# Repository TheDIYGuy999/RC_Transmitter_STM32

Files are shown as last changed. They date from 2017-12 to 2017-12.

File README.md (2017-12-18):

# This is an Arduino 2.4GHz radio and IR transmitter for STM32
## Features:
- IR transmitter for "LEGO" Powerfunctions and trains as well as for "MECCANO" motors
- 2.4GHz radio transmitter for RC cars, helicopters etc.
- 4 analog axes, 2 mode switches (joystick buttons)
- 1 potentiometer for adjustments like the MRSC stability control
- 4 push buttons for transmission mode and vehicle selection as well as menu navigation
- 10 seletcable vehicle addresses, so you can use it for more than one vehicle
- 3.3V, 72MHz STM32F103C8T6 ARM board
- Atmel AVR version see: https://github.com/TheDIYGuy999/RC_Transmitter
- 2.4GHz NRF24L01 radio module
- Support for 0.96" I2C OLED.
- Configuration menu for: Channel direction reversing, servo travel adjustment (independent for each vehicle)
- Configuration values are stored in EEPROM
- NRF24L01+PA+LNA SMA radio modules with power amplifier are supported from board version 1.1
- very compact
- Eagle schematic will follow
- PONG Game included (runs much faster than on the Atmel AVR version)

## Changelog:

New in V 2.0:
- Initial commit starting with V2.0, because the features are the same as in V2.0 for Atmel ARM MCU's
- Pinout according to the software comments. An Eagle schematic will follow later
- Works together with my Atmel AVR based receivers or the transmitter in "Tester Mode"
- OLED now driven by the u8g2 library in "full buffer" mode. This is much faster, but requires more RAM (no problem on the STM32)
- Lego IR ist tested
- Meccano IR should work in theory, but the signal was only tested with an oscilloscope
- The emulated STM32 EEPROM seems to work properly, but the required "eepromHandler.h" is entirely new
- This version may still contain bugs. It was only tested on a breadboard

New in V 2.01:
- Battery voltage detection bug fixed

## Usage

See pictures

The biggest and the smallest vehicle:


The Atmel AVR version:


The STM32 test rig on a breadboard:
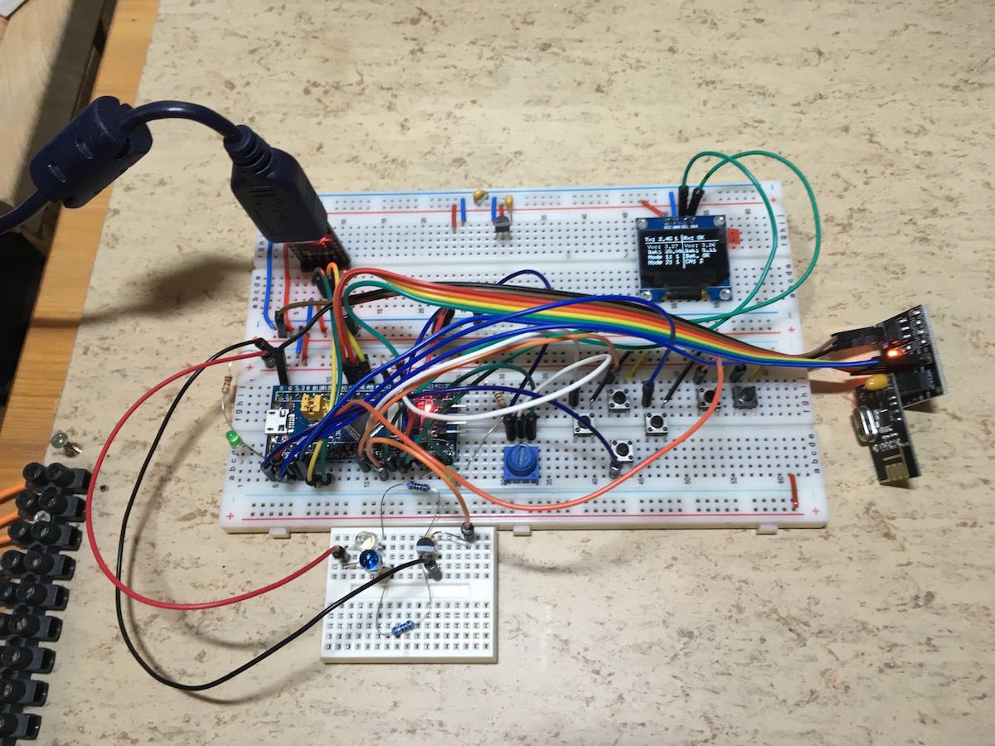
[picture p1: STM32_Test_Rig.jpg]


(c) 2017 TheDIYGuy999

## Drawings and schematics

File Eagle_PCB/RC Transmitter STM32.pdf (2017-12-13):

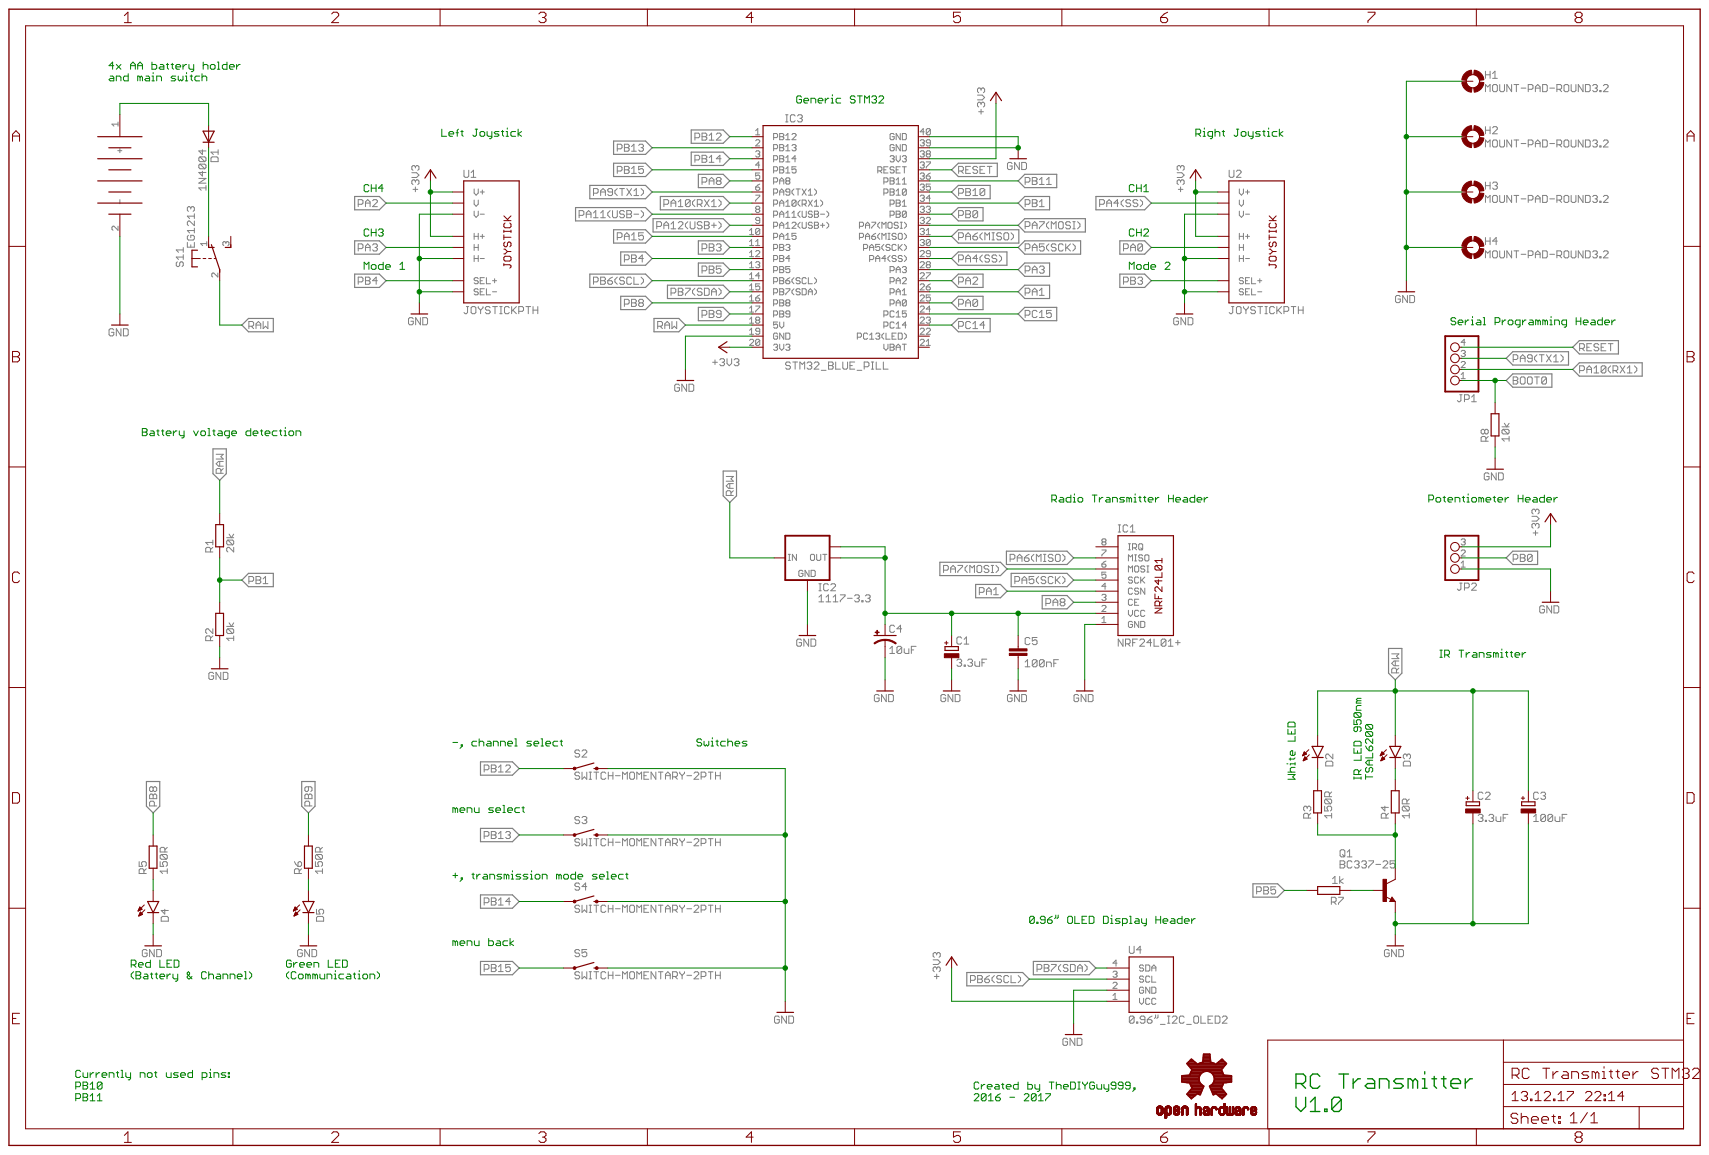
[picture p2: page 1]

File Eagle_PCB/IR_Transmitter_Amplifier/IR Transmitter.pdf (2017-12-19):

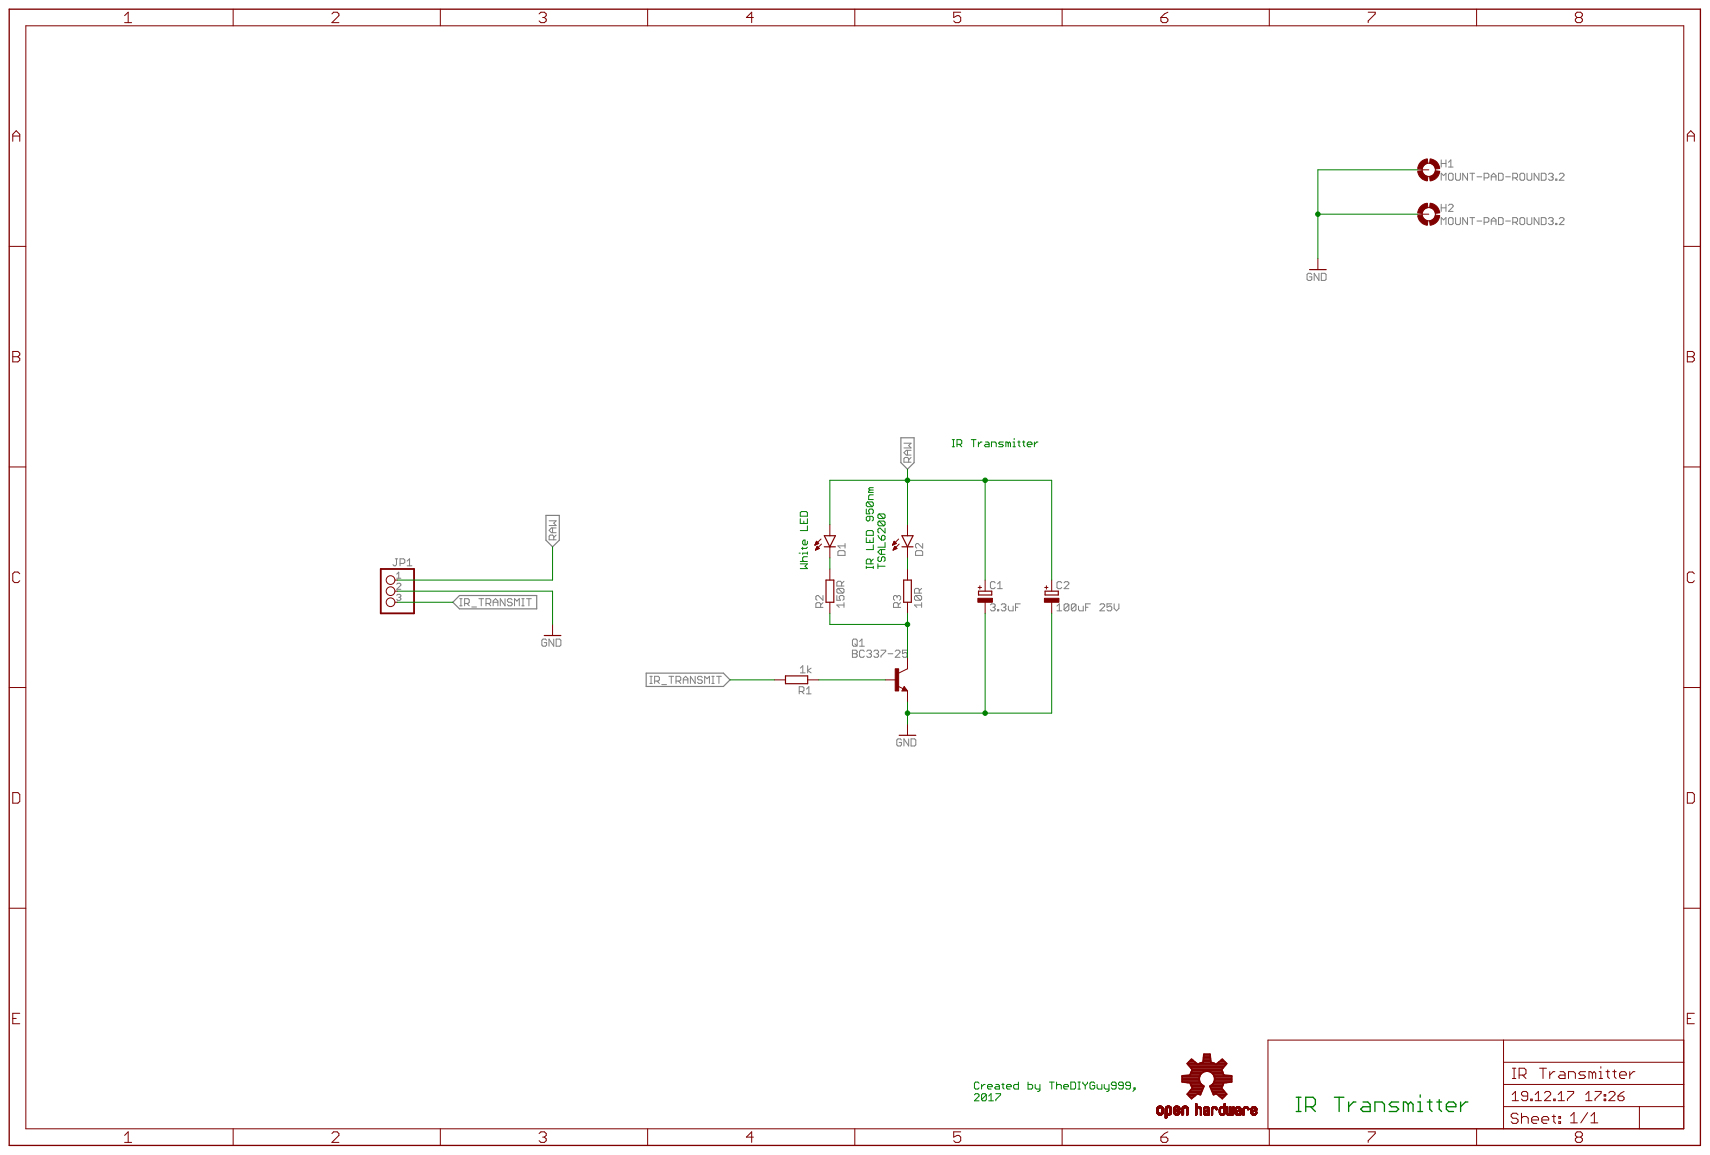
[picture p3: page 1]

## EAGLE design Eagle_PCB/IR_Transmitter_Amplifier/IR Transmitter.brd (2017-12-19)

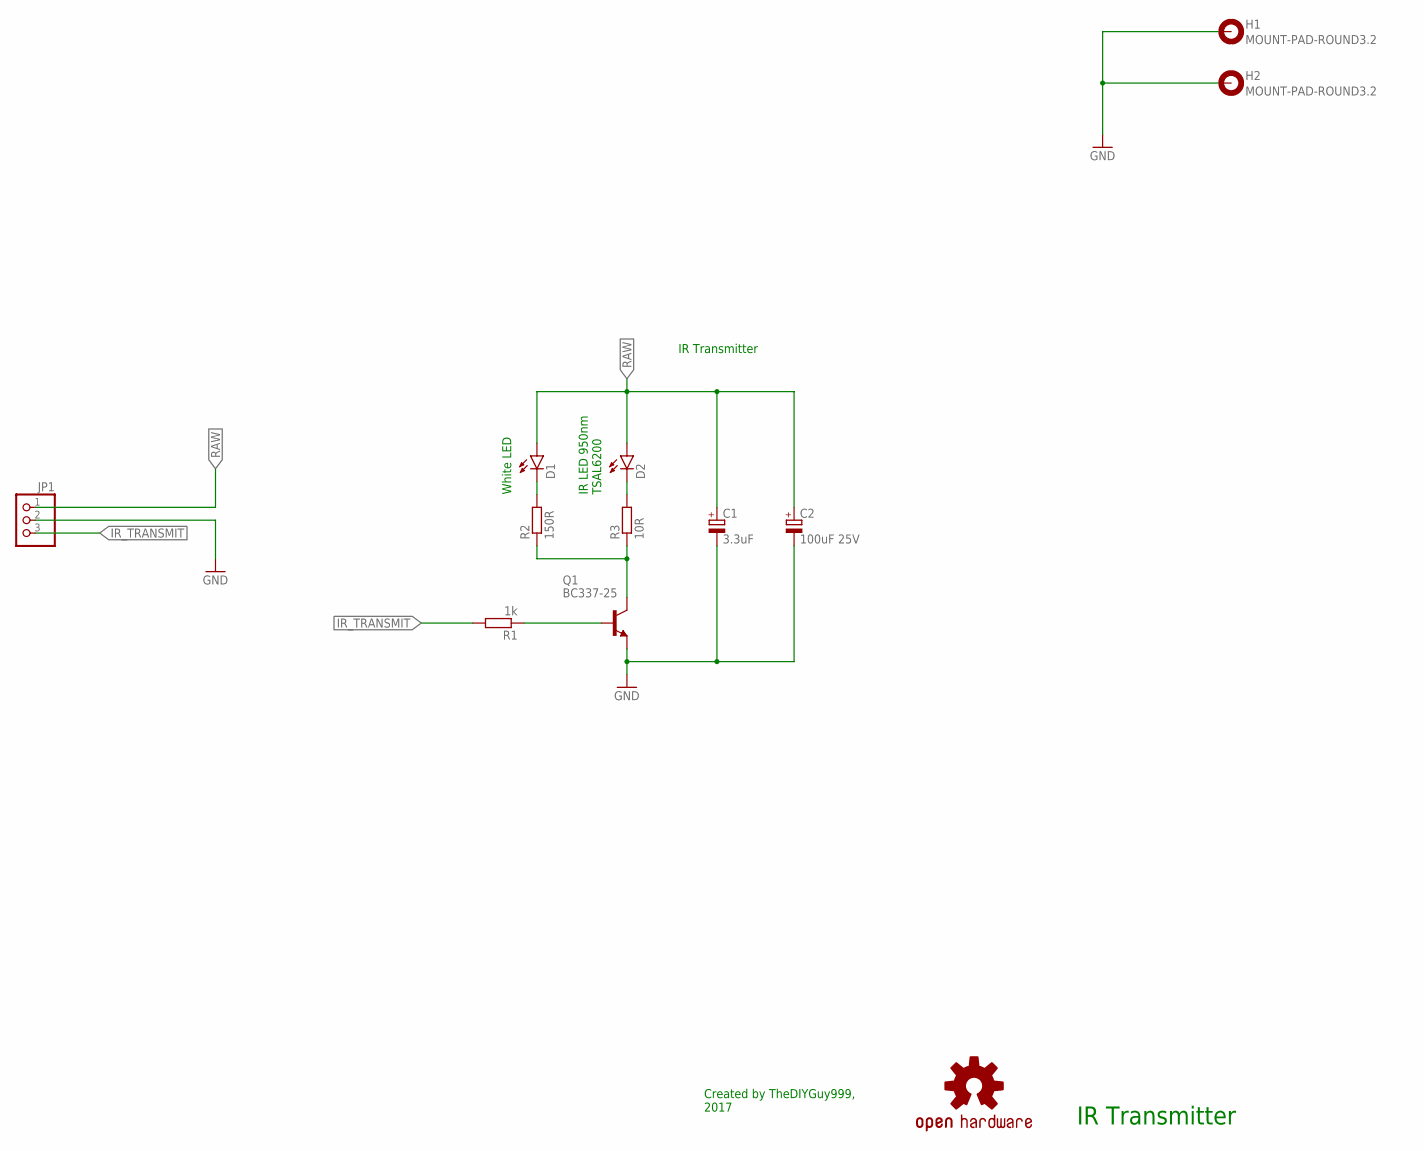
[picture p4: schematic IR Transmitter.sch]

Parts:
C1: 3.3uF; B45181A
C2: 100uF 25V; E2,5-7
D1, D2: LED5MM
H1, H2: MOUNT-PAD-ROUND3.2; 3,2-PAD
JP1: PINHD-1X3; 1X03
LOGO1: OSHW-LOGOM; OSHW-LOGO-M
Q1: BC337-25; TO92
R1: 1k; 0207/2V
R2: 150R; 0207/2V
R3: 10R; 0207/2V

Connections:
GND: C1.-, C2.-, H1.B3,2, H2.B3,2, JP1.2, Q1.1 (E)
IR_TRANSMIT: JP1.3, R1.2
unnamed: Q1.3 (C), R2.1, R3.1
unnamed: D2.K (C), R3.2
unnamed: Q1.2 (B), R1.1
unnamed: D1.K (C), R2.2
RAW: C1.+, C2.+, D1.A, D2.A, JP1.1

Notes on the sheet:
IR Transmitter
White LED
IR LED 950nm TSAL6200
Created by TheDIYGuy999, 2017

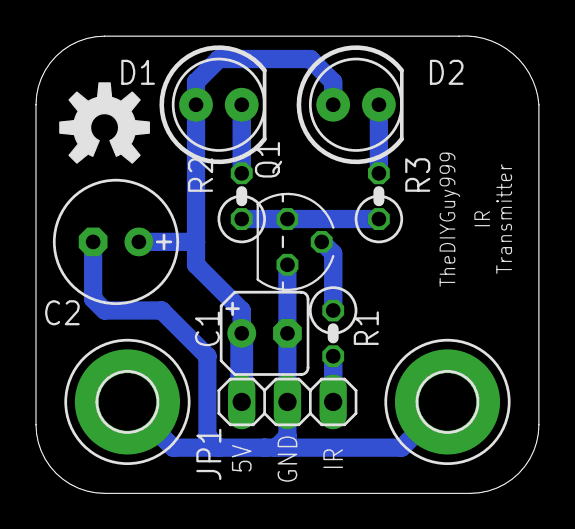
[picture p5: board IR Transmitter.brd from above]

Board: 2 copper layers, 27.9 x 25.4 mm, 12 parts (0 on the bottom side), 7 nets.

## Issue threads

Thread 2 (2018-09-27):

Receiver for stm32

yudimoss, 2018-09-27:
Would you mind to make arduino radio 2.4ghz receiver for stm32?

TheDIYGuy999, 2018-09-28:
I don't see the point. The ATmega328P has more than enough processing power for the receiver. The existing Micro RC receiver is fully compatible with the STM32 transmitter.

yudimoss, 2018-09-28:
Oh I see

Closed 2018-09-28.

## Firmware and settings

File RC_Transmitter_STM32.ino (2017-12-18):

// Micro RC Project. A tiny little 2.4GHz and LEGO "Power Functions" / "MECCANO" IR RC transmitter!
// 3.3V, 72MHz STM32F103C8T6 ARM board
// Atmel AVR version see: https://github.com/TheDIYGuy999/RC_Transmitter
// 2.4GHz NRF24L01 radio module
// SSD 1306 128 x 63 0.96" OLED
// Custom PCB will follow
// Menu for the following adjustments:
// -Channel reversing
// -Channel travel limitation adjustable in steps of 5%
// -Value changes are stored in EEPROM, individually per vehicle
// Radio transmitter tester included (press "Select" button during power up)
// NRF24L01+PA+LNA SMA radio modules with power amplifier are also supported
// ATARI PONG game :-) Press the "Back" button during power on to start it

const float codeVersion = 2.01; // Software revision

//
// =======================================================================================================
// BUILD OPTIONS (comment out unneeded options)
// =======================================================================================================
//

//#define DEBUG // if not commented out, Serial.print() is active! For debugging only!!
//#define OLED_DEBUG // if not commented out, an additional diagnostics screen is shown during startup

//
// =======================================================================================================
// INCLUDE LIRBARIES
// =======================================================================================================
//

// Libraries
#include <Wire.h>
#include <SPI.h>
#include <RF24_STM32.h> // https://github.com/TheDIYGuy999/RF24_STM32
#include <EEPROM.h> // Part of https://github.com/rogerclarkmelbourne/Arduino_STM32
#include <LegoIr.h> // https://github.com/TheDIYGuy999/LegoIr
#include <statusLED.h> // https://github.com/TheDIYGuy999/statusLED
#include <U8g2lib.h> // https://github.com/olikraus/u8g2

// Tabs (.h files in the sketch directory) see further down

//
// =======================================================================================================
// PIN ASSIGNMENTS & GLOBAL VARIABLES
// =======================================================================================================
//

// Is the radio or IR transmission mode active?
byte transmissionMode = 1; // Radio mode is active by default

// Select operation trannsmitter operation mode
byte operationMode = 0; // Start in transmitter mode (0 = transmitter mode, 1 = tester mode, 2 = game mode)

// Vehicle address
int vehicleNumber = 1; // Vehicle number one is active by default

// Radio channels (126 channels are supported)
byte chPointer = 0; // Channel 1 (the first entry of the array) is active by default
const byte NRFchannel[] {
  1, 2
};

// the ID number of the used "radio pipe" must match with the selected ID on the transmitter!
// 10 ID's are available @ the moment
const uint64_t pipeOut[] = {
  0xE9E8F0F0B1LL, 0xE9E8F0F0B2LL, 0xE9E8F0F0B3LL, 0xE9E8F0F0B4LL, 0xE9E8F0F0B5LL,
  0xE9E8F0F0B6LL, 0xE9E8F0F0B7LL, 0xE9E8F0F0B8LL, 0xE9E8F0F0B9LL, 0xE9E8F0F0B0LL
};
const int maxVehicleNumber = (sizeof(pipeOut) / (sizeof(uint64_t)));

// Hardware configuration: Set up nRF24L01 radio on hardware SPI bus & pins PA8 (CE) & PA1 (CSN)
RF24 radio(PA8, PA1);

// The size of this struct should not exceed 32 bytes
struct RcData {
  byte axis1; // Aileron (Steering for car)
  byte axis2; // Elevator
  byte axis3; // Throttle
  byte axis4; // Rudder
  boolean mode1 = false; // Mode1 (toggle speed limitation)
  boolean mode2 = false; // Mode2 (toggle acc. / dec. limitation)
  boolean momentary1 = false; // Momentary push button
  byte pot1; // Potentiometer
} __attribute__((packed, aligned(2))); // no padding, aligned to an address that is divisible by 2 (keeps it compatible with AVR)
RcData data;

// This struct defines data, which are embedded inside the ACK payload
struct ackPayload {
  float vcc; // vehicle vcc voltage
  float batteryVoltage; // vehicle battery voltage
  boolean batteryOk; // the vehicle battery voltage is OK!
  byte channel = 1; // the channel number
} __attribute__((packed, aligned(2))); // no padding, aligned to an address that is divisible by 2 (keeps it compatible with AVR)
ackPayload payload;

// Did the receiver acknowledge the sent data?
boolean transmissionState;

// LEGO powerfunctions IR
LegoIr pf;
int pfChannel;
const int pfMaxAddress = 3;

// Configuration arrays
const int servos = 4;
const byte entries = 44; // Entries per array

//Joystick reversing
uint16_t joystickReversed[maxVehicleNumber + 1][servos] = { // 1 + 10 Vehicle Addresses, 4 Servos
  {false, false, false, false}, // Address 0 used for EEPROM initialisation

  {false, false, false, false}, // Address 1
  {false, false, false, false}, // Address 2
  {false, false, false, false}, // Address 3
  {false, false, false, false}, // Address 4
  {false, false, false, false}, // Address 5
  {false, false, false, false}, // Address 6
  {false, false, false, false}, // Address 7
  {false, false, false, false}, // Address 8
  {false, false, false, false}, // Address 9
  {false, false, false, false}, // Address 10
};

//Joystick percent negative
uint16_t joystickPercentNegative[maxVehicleNumber + 1][servos] = { // 1 + 10 Vehicle Addresses, 4 Servos
  {100, 100, 100, 100}, // Address 0 not used

  {100, 100, 100, 100}, // Address 1
  {100, 100, 100, 100}, // Address 2
  {100, 100, 100, 100}, // Address 3
  {100, 100, 100, 100}, // Address 4
  {100, 100, 100, 100}, // Address 5
  {100, 100, 100, 100}, // Address 6
  {100, 100, 100, 100}, // Address 7
  {100, 100, 100, 100}, // Address 8
  {100, 100, 100, 100}, // Address 9
  {100, 100, 100, 100}, // Address 10
};

//Joystick percent positive
uint16_t joystickPercentPositive[maxVehicleNumber + 1][servos] = { // 1 + 10 Vehicle Addresses, 4 Servos
  {100, 100, 100, 100}, // Address 0 not used

  {100, 100, 100, 100}, // Address 1
  {100, 100, 100, 100}, // Address 2
  {100, 100, 100, 100}, // Address 3
  {100, 100, 100, 100}, // Address 4
  {100, 100, 100, 100}, // Address 5
  {100, 100, 100, 100}, // Address 6
  {100, 100, 100, 100}, // Address 7
  {100, 100, 100, 100}, // Address 8
  {100, 100, 100, 100}, // Address 9
  {100, 100, 100, 100}, // Address 10
};

// TX voltages
boolean batteryOkTx = false;
#define BATTERY_DETECT_PIN PB1 // The 20k & 10k battery detection voltage divider is connected to pin PB1
float txVcc;
float txBatt;

// Joysticks
#define JOYSTICK_1 PA4
#define JOYSTICK_2 PA0
#define JOYSTICK_3 PA3
#define JOYSTICK_4 PA2

// Potentiometer
#define POT_1 PB0

// Joystick push buttons
#define JOYSTICK_BUTTON_LEFT PB4
#define JOYSTICK_BUTTON_RIGHT PB3

byte leftJoystickButtonState;
byte rightJoystickButtonState;

// Buttons
#define BUTTON_LEFT PB12 // - or channel select
#define BUTTON_RIGHT PB14 // + or transmission mode select
#define BUTTON_SEL PB13 // select button for menu
#define BUTTON_BACK PB15 // back button for menu

byte leftButtonState = 7; // init states with 7 (see macro below)!
byte rightButtonState = 7;
byte selButtonState = 7;
byte backButtonState = 7;

// macro for detection of rising edge and debouncing
/*the state argument (which must be a variable) records the current and the last 3 reads
  by shifting one bit to the left at each read and bitwise anding with 15 (=0b1111).
  If the value is 7(=0b0111) we have one raising edge followed by 3 consecutive 1's.
  That would qualify as a debounced raising edge*/
#define DRE(signal, state) (state=(state<<1)|(signal&1)&15)==7

// Status LED objects (false = not inverted)
statusLED greenLED(false); // green: ON = ransmitter ON, flashing = Communication with vehicle OK
statusLED redLED(false); // red: ON = battery empty

// OLED display SSD1306
// SDA = PB7, SCL = PB6 (Hardware I2C)
U8G2_SSD1306_128X64_NONAME_F_HW_I2C u8g2(U8G2_R0, /* reset=*/ U8X8_PIN_NONE);

int activeScreen = 0; // the currently displayed screen number (0 = splash screen)
boolean displayLocked = true;
byte menuRow = 0; // Menu active cursor line

//
// =======================================================================================================
// INCLUDE TABS (header files in sketch directory)
// =======================================================================================================
//

#include "readVCC.h"
#include "eepromHandler.h"
#include "transmitterConfig.h"
#include "MeccanoIr.h" // https://github.com/TheDIYGuy999/MeccanoIr
#include "pong.h" // A little pong game :-)

//
// =======================================================================================================
// RADIO SETUP
// =======================================================================================================
//

void setupRadio() {
  radio.begin();
  radio.setChannel(NRFchannel[chPointer]);

  radio.powerUp();

  // Set Power Amplifier (PA) level to one of four levels: RF24_PA_MIN, RF24_PA_LOW, RF24_PA_HIGH and RF24_PA_MAX
  if (boardVersion < 1.1 ) radio.setPALevel(RF24_PA_MIN); // No independent NRF24L01 3.3 PSU, so only "MIN" transmission level allowed
  else radio.setPALevel(RF24_PA_MAX); // Independent NRF24L01 3.3 PSU, so "FULL" transmission level allowed

  radio.setDataRate(RF24_250KBPS);
  radio.setAutoAck(pipeOut[vehicleNumber - 1], true); // Ensure autoACK is enabled
  radio.enableAckPayload();
  radio.enableDynamicPayloads();
  radio.setRetries(5, 5);                  // 5x250us delay (blocking!!), max. 5 retries
  //radio.setCRCLength(RF24_CRC_8);          // Use 8-bit CRC for performance*/

#ifdef DEBUG
  radio.printDetails();
  delay(1800);
#endif

  // All axes to neutral position
  data.axis1 = 50;
  data.axis2 = 50;
  data.axis3 = 50;
  data.axis4 = 50;

  // Transmitter
  if (operationMode == 0) {
    radio.openWritingPipe(pipeOut[vehicleNumber - 1]); // Vehicle Number 1 = Array number 0, so -1!
    radio.write(&data, sizeof(RcData));
  }

  // Receiver (radio tester mode)
  if (operationMode == 1) {
    radio.openReadingPipe(1, pipeOut[vehicleNumber - 1]);
    radio.startListening();
  }
}

//
// =======================================================================================================
// LEGO POWERFUNCTIONS SETUP
// =======================================================================================================
//

void setupPowerfunctions() {
  pfChannel = vehicleNumber - 1;  // channel 0 - 3 is labelled as 1 - 4 on the LEGO devices!

  if (pfChannel > pfMaxAddress) pfChannel = pfMaxAddress;

  pf.begin(PB5, pfChannel);  // Pin PB5, channel 0 - 3
}

//
// =======================================================================================================
// MAIN ARDUINO SETUP (1x during startup)
// =======================================================================================================
//

void setup() {

#ifdef DEBUG
  Serial.begin(115200);
  printf_begin();
  delay(3000);
#endif

  // Disable STM32 JTAG debug pins! Allows to use pin PB3 and PB4
  // See: http://www.stm32duino.com/viewtopic.php?f=3&t=2084&p=27945&hilit=pb3#p27916
  disableDebugPorts();

  // ADC setup for VCC readout
  setup_vcc_sensor();

  // LED setup
  greenLED.begin(PB9); // Green LED on pin PB9
  redLED.begin(PB8); // Red LED on pin PB8

  // Pinmodes (all other pinmodes are handled inside libraries)
  pinMode(JOYSTICK_BUTTON_LEFT, INPUT_PULLUP);
  pinMode(JOYSTICK_BUTTON_RIGHT, INPUT_PULLUP);
  pinMode(BUTTON_LEFT, INPUT_PULLUP);
  pinMode(BUTTON_RIGHT, INPUT_PULLUP);
  pinMode(BUTTON_SEL, INPUT_PULLUP);
  pinMode(BUTTON_BACK, INPUT_PULLUP);

  pinMode(JOYSTICK_1, INPUT_ANALOG);
  pinMode(JOYSTICK_2, INPUT_ANALOG);
  pinMode(JOYSTICK_3, INPUT_ANALOG);
  pinMode(JOYSTICK_4, INPUT_ANALOG);

  pinMode(POT_1, INPUT_ANALOG);

  // EEPROM setup
  setupEeprom();

  if (joystickReversed[0][0] || (!digitalRead(BUTTON_BACK) && !digitalRead(BUTTON_SEL))) { // 65535 is EEPROM default after a program download,
    // this indicates that we have to initialise the EEPROM with our default values! Or manually triggered with
    // both "SEL" & "BACK" buttons pressed during switching on!
    writeEepromDefaults(); // then write defaults to EEPROM
    readEeprom(); // and fill the arrays with the new EEPROM values!

  }

  // Switch to radio tester mode, if "Select" button is pressed
  if (digitalRead(BUTTON_BACK) && !digitalRead(BUTTON_SEL)) {
    operationMode = 1;
  }

  // Switch to game mode, if "Back" button is pressed
  if (!digitalRead(BUTTON_BACK) && digitalRead(BUTTON_SEL)) {
    operationMode = 2;
  }

  // Joystick setup
  JoystickOffset(); // Compute all joystick center points
  readJoysticks(); // Then do the first jocstick read

  // Radio setup
  setupRadio();

  // LEGO Powerfunctions setup
  setupPowerfunctions();

  // Display setup
  u8g2.begin();
  u8g2.setFontRefHeightExtendedText();
  u8g2.setFont(u8g_font_6x10);

  // Splash screen
  checkBattery();
  activeScreen = 0; // 0 = splash screen active
  drawDisplay();
#ifdef OLED_DEBUG
  activeScreen = 100; // switch to the diagnostics screen
  delay(1500);
  drawDisplay();
#endif
  activeScreen = 1; // switch to the main screen
  delay(1500);
}

//
// =======================================================================================================
// BUTTONS
// =======================================================================================================
//

// Sub function for channel travel adjustment and limitation --------------------------------------
void travelAdjust(boolean upDn) {
  int16_t inc = 5;
  if (upDn) inc = 5; // Direction +
  else inc = -5; // -

  if ( (menuRow & 0x01) == 0) {// even (2nd column)
    joystickPercentPositive[vehicleNumber][(menuRow - 6) / 2 ] += inc; // row 6 - 12 = 0 - 3
  }
  else { // odd (1st column)
    joystickPercentNegative[vehicleNumber][(menuRow - 5) / 2 ] += inc;  // row 5 - 11 = 0 - 3
  }
  joystickPercentPositive[vehicleNumber][(menuRow - 6) / 2 ] = constrain(joystickPercentPositive[vehicleNumber][(menuRow - 6) / 2 ], 20, 100);
  joystickPercentNegative[vehicleNumber][(menuRow - 5) / 2 ] = constrain(joystickPercentNegative[vehicleNumber][(menuRow - 5) / 2 ], 20, 100);
}

// Main buttons function --------------------------------------------------------------------------
void readButtons() {

  // Every 10 ms
  static unsigned long lastTrigger;
  if (millis() - lastTrigger >= 10) {
    lastTrigger = millis();

    // Left joystick button (Mode 1)
    if (DRE(digitalRead(JOYSTICK_BUTTON_LEFT), leftJoystickButtonState) && (transmissionMode == 1)) {
      data.mode1 = !data.mode1;
      drawDisplay();
    }

    // Right joystick button (Mode 2)
    if (DRE(digitalRead(JOYSTICK_BUTTON_RIGHT), rightJoystickButtonState) && (transmissionMode == 1)) {
      data.mode2 = !data.mode2;
      drawDisplay();
    }

    if (activeScreen <= 10) { // if menu is not displayed ----------

      // Left button: Channel selection
      if (DRE(digitalRead(BUTTON_LEFT), leftButtonState) && (transmissionMode < 3)) {
        vehicleNumber ++;
        if (vehicleNumber > maxVehicleNumber) vehicleNumber = 1;
        setupRadio(); // Re-initialize the radio with the new pipe address
        setupPowerfunctions(); // Re-initialize the LEGO IR transmitter with the new channel address
        drawDisplay();
      }

      // Right button: Change transmission mode. Radio <> IR
      if (infrared) { // only, if transmitter has IR option
        if (DRE(digitalRead(BUTTON_RIGHT), rightButtonState)) {
          if (transmissionMode < 3) transmissionMode ++;
          else {
            transmissionMode = 1;
            setupRadio(); // Re-initialize radio, if we switch back to radio mode!
          }
          drawDisplay();
        }
      }
    }
    else { // if menu is displayed -----------
      // Left button: Value -
      if (DRE(digitalRead(BUTTON_LEFT), leftButtonState)) {
        if (activeScreen == 11) {
          joystickReversed[vehicleNumber][menuRow - 1] = false;
        }
        if (activeScreen == 12) {
          travelAdjust(false); // -
        }
        drawDisplay();
      }

      // Right button: Value +
      if (DRE(digitalRead(BUTTON_RIGHT), rightButtonState)) {
        if (activeScreen == 11) {
          joystickReversed[vehicleNumber][menuRow - 1] = true;
        }
        if (activeScreen == 12) {
          travelAdjust(true); // +
        }
        drawDisplay();
      }
    }

    // Menu buttons:

    // Select button: opens the menu and scrolls through menu entries
    if (DRE(digitalRead(BUTTON_SEL), selButtonState) && (transmissionMode == 1)) {
      activeScreen = 11; // 11 = Menu screen 1
      menuRow ++;
      if (menuRow > 4) activeScreen = 12; // 12 = Menu screen 2
      if (menuRow > 12) {
        activeScreen = 11; // Back to menu 1, entry 1
        menuRow = 1;
      }
      drawDisplay();
    }

    // Back / Momentary button:
    if (activeScreen <= 10) { // Momentary button, if menu is NOT displayed
      if (!digitalRead(BUTTON_BACK)) data.momentary1 = true;
      else data.momentary1 = false;
    }
    else { // Goes back to the main screen & saves the changed entries in the EEPROM
      if (DRE(digitalRead(BUTTON_BACK), backButtonState)) {
        activeScreen = 1; // 1 = Main screen
        menuRow = 0;
        drawDisplay();
        writeEeprom(); // update changed values in EEPROM
      }
    }
  }
}

//
// =======================================================================================================
// JOYSTICKS
// =======================================================================================================
//

int offset[4]; // the auto calibration offset of each joystick

// Auto-zero subfunction (called during setup) ----
void JoystickOffset() {
  offset[0] = 2047 - analogRead(JOYSTICK_1);
  offset[1] = 2047 - analogRead(JOYSTICK_2);
  offset[2] = 2047 - analogRead(JOYSTICK_3);
  offset[3] = 2047 - analogRead(JOYSTICK_4);
}

// Mapping and reversing subfunction ----
byte mapJoystick(byte input, byte arrayNo) {
  int reading[4];
  reading[arrayNo] = analogRead(input) + offset[arrayNo]; // read joysticks and add the offset
  reading[arrayNo] = constrain(reading[arrayNo], (4095 - range), range); // then limit the result before we do more calculations below

#ifdef CONFIG_2_CH // In most "car style" transmitters, less than a half of the throttle potentiometer range is used for the reverse. So we have to enhance this range!
  if (reading[2] < (range / 2) ) {
    reading[2] = constrain(reading[2], (range / 3), (range / 2)); // limit reverse range, which will be multiplied later
    reading[2] = map(reading[2], (range / 3), (range / 2), 0, (range / 2)); // reverse range multiplied by 4
  }
#endif

  if (transmissionMode == 1 && operationMode != 2 ) { // Radio mode and not game mode
    if (joystickReversed[vehicleNumber][arrayNo]) { // reversed
      return map(reading[arrayNo], (4095 - range), range, (joystickPercentPositive[vehicleNumber][arrayNo] / 2 + 50), (50 - joystickPercentNegative[vehicleNumber][arrayNo] / 2));
    }
    else { // not reversed
      return map(reading[arrayNo], (4095 - range), range, (50 - joystickPercentNegative[vehicleNumber][arrayNo] / 2), (joystickPercentPositive[vehicleNumber][arrayNo] / 2 + 50));
    }
  }
  else { // IR mode
    return map(reading[arrayNo], (4095 - range), range, 0, 100);
  }
}

// Main Joystick function ----
void readJoysticks() {

  // save previous joystick positions
  byte previousAxis1 = data.axis1;
  byte previousAxis2 = data.axis2;
  byte previousAxis3 = data.axis3;
  byte previousAxis4 = data.axis4;

  // Read current joystick positions, then scale and reverse output signals, if necessary (only for the channels we have)
#ifdef CH1
  data.axis1 = mapJoystick(JOYSTICK_1, 0); // Aileron (Steering for car)
#endif

#ifdef CH2
  data.axis2 = mapJoystick(JOYSTICK_2, 1); // Elevator
#endif

#ifdef CH3
  data.axis3 = mapJoystick(JOYSTICK_3, 2); // Throttle
#endif

#ifdef CH4
  data.axis4 = mapJoystick(JOYSTICK_4, 3); // Rudder
#endif

  // Only allow display refresh, if no value has changed!
  if (previousAxis1 != data.axis1 ||
      previousAxis2 != data.axis2 ||
      previousAxis3 != data.axis3 ||
      previousAxis4 != data.axis4) {
    displayLocked = true;
  }
  else {
    displayLocked = false;
  }
}

//
// =======================================================================================================
// POTENTIOMETER
// =======================================================================================================
//

void readPotentiometer() {
  data.pot1 = map(analogRead(POT_1), 0, 4095, 0, 100);
  data.pot1 = constrain(data.pot1, 0, 100);
}

//
// =======================================================================================================
// TRANSMIT LEGO POWERFUNCTIONS IR SIGNAL
// =======================================================================================================
//
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
void loop() {

  // only read analog inputs in transmitter (0) or game mode (2)
  if (operationMode == 0 || operationMode == 2) {

    // Read joysticks
    readJoysticks();

    // Read Potentiometer
    readPotentiometer();
  }

  // Transmit data via infrared or 2.4GHz radio
  if (operationMode == 1) readRadio(); // 2.4 GHz radio tester
  if (operationMode == 0) {
    transmitRadio(); // 2.4 GHz radio
    if (transmissionMode == 2) transmitLegoIr(); // LEGO Infrared
    if (transmissionMode == 3) transmitMeccanoIr(); // MECCANO Infrared
  }

  // Refresh display every 50 ms in tester mode 1 (in radio mode 0 only, if value has changed)
  static unsigned long lastDisplay;
  if (operationMode == 1 && millis() - lastDisplay >= 50) {
    lastDisplay = millis();
    drawDisplay();
  }

  // Atari Pong game :-)
  if (operationMode == 2) pong();

  // If not in game mode:
  else {
    led(); // LED control
    checkBattery(); // Check battery
    readButtons();
  }
}

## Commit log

2017-12-13 Schematic, board file will follow later
2017-12-18 V2.01: Battery voltage detection bug fixed
    [RC_Transmitter_STM32.ino]
2017-12-19 Small IR transmitter with amplifier
    [IR Transmitter.brd, IR Transmitter.sch]

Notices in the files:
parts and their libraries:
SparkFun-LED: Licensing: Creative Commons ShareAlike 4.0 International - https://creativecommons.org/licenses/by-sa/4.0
